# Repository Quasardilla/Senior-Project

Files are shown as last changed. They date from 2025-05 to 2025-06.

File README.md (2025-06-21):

# Haptic Feedback Remote
This "remote" is a design concept that utilizes a touchpad as opposed to a D-pad with the intention to control a tv (although this concept doesn't include any of the hardware required for communication). Based on inputs, the remote will vibrate in specific patterns (haptic feedback) in order to simulate certain feelings like a click or a scroll. 

# Features
Click: When the touchpad is pressed and released, the voice coil will give a kick accompanied by a little chirp

Scroll: When the touchpad is pressed and moved across, the voice coil gives a very light kick for every movement in the X or Y direction

Simulated Scroll: When the touchpad is being scrolled across, and the user lets go, the micro calculates how often a scroll click should happen given the velocity of the movement before it was released. The voice coil reacts as though it's scrolling from an actual interaction

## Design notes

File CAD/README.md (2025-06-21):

# CAD
All of the models that were used in this project were designed in OnShape. Since the platform doesn't export entire projects, I won't post the files here.
You can check out the CAD at [OnShape](https://cad.onshape.com/documents/ba6eefc270d24b4c9dd6e786/w/6963f8d8a0a2caa2323001ec/e/34bf19d81762a19b936466c0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), and if you make an account you can download all the models.

## The CAD includes:

The shell (top and bottom), which slides together

The touchpad bracket that keeps the touchpad in place

Demo pcb's so I could figure out how the pcbs would fit before I ordered them

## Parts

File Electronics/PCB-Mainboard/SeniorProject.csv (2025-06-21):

Reference | Qty | Value | DNP | Exclude from BOM | Exclude from Board | Footprint | Datasheet
C1,C2 | 2 | 0.1uF |  |  |  | Capacitor_SMD:C_0201_0603Metric | ~
C3,C4 | 2 | 10uF |  |  |  | Capacitor_SMD:CP_Elec_4x4.5 | ~
J1 | 1 | 1-2483180-2 |  |  |  | SamacSys IMPORTED:1-2483180-2 | https://www.te.com/commerce/DocumentDelivery/DDEController?Action=showdoc
M1 | 1 | Motor_DC |  |  |  | Resistor_SMD:R_2816_7142Metric_Pad3.20x4.45mm_HandSolder | ~
Q1 | 1 | SS8550 |  |  |  | Package_TO_SOT_SMD:SOT-416 | http://www.secosgmbh.com/datasheet/products/SSMPTransistor/SOT-23/SS8550.pdf
R1,R3,R4 | 3 | 10k |  |  |  | Resistor_SMD:R_0201_0603Metric | ~
R2 | 1 | 75k |  |  |  | Resistor_SMD:R_0201_0603Metric | ~
R5,R6 | 2 | R |  |  |  | Resistor_SMD:R_0201_0603Metric | ~
R7,R8 | 2 | 100 |  |  |  | Resistor_SMD:R_0201_0603Metric | ~
STRAIN1,STRAIN2 | 2 | ~ |  |  |  | Resistor_SMD:R_2816_7142Metric_Pad3.20x4.45mm_HandSolder | ~
U1 | 1 | Teensy 4.0 |  |  |  | Teensy 4.0:MODULE_Teensy 4.0
U2 | 1 | HX711 |  |  |  | Package_SO:SOP-16_3.9x9.9mm_P1.27mm | https://web.archive.org/web/20220615044707/https://akizukidenshi.com/download/ds/avia/hx711.pdf
U3 | 1 | MPR121QR2 |  |  |  | Package_DFN_QFN:UQFN-20_3x3mm_P0.4mm | https://resurgentsemi.com/wp-content/uploads/2018/09/MPR121_rev5-Resurgent.pdf?d453f8&d453f8

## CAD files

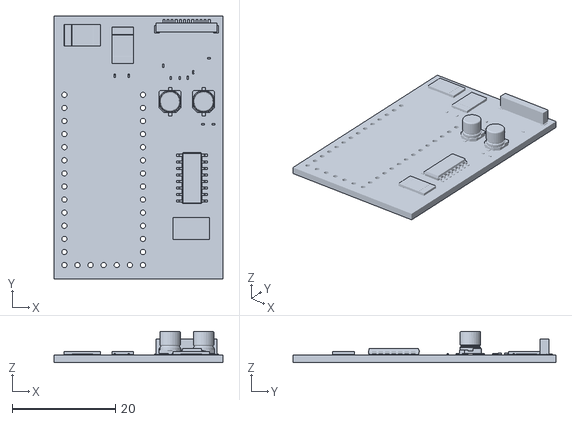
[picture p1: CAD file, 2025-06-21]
Electronics/PCB-Mainboard/SeniorProject.stl
32.8 x 51.0 x 6.09

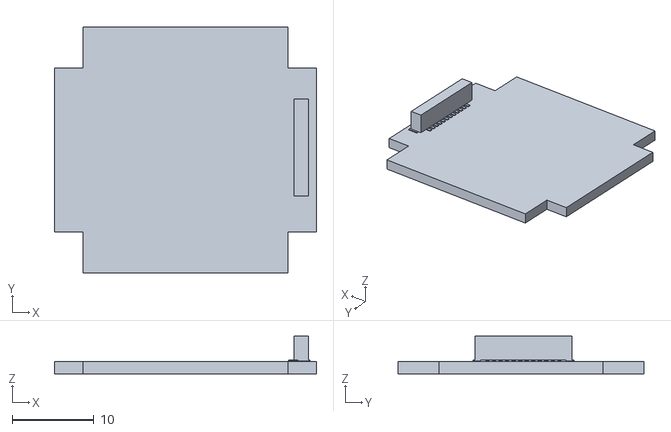
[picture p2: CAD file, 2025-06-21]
Electronics/PCB-Touchpad/SeniorProjectTouchpad.stl
32.0 x 30.0 x 4.59

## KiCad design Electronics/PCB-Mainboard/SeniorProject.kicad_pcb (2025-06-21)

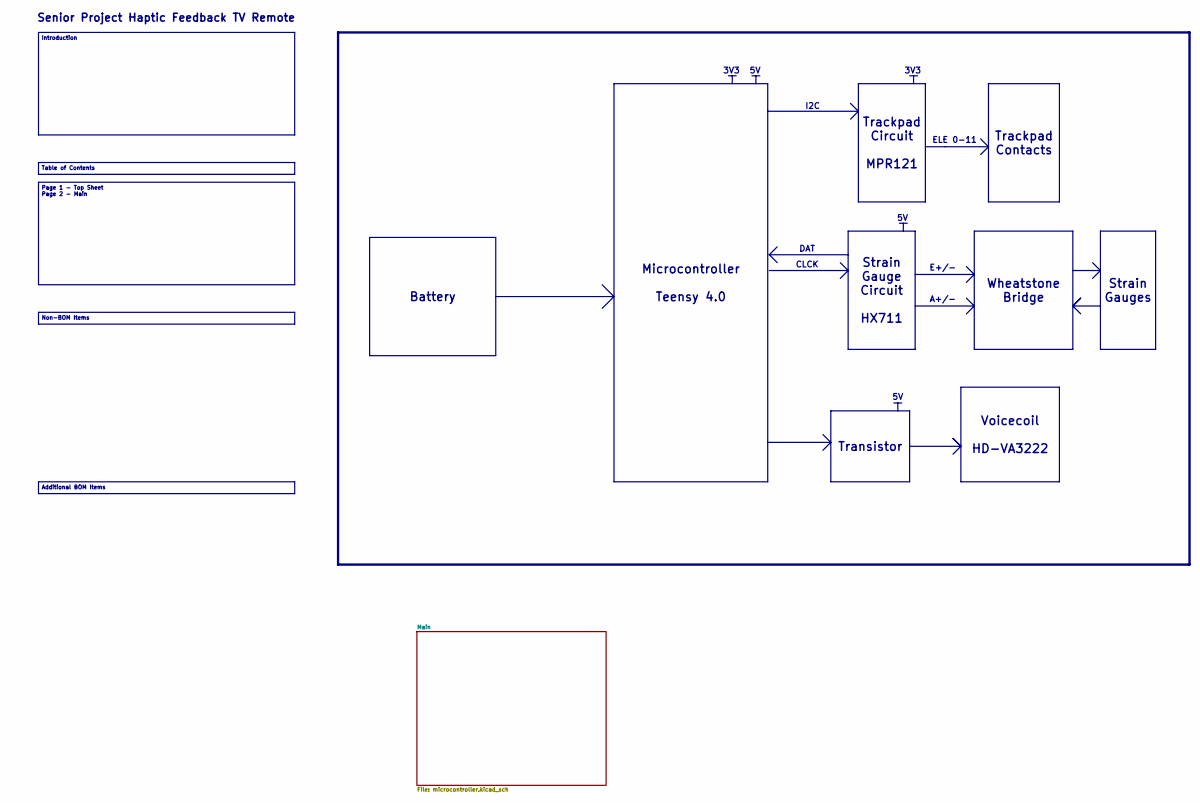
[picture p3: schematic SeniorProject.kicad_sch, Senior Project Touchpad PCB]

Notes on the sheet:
A+/-
CLCK
ELE 0-11
3V3
I2C
E+/-
Senior Project Haptic Feedback TV Remote
DAT
Table of Contents
Battery
Transistor
Trackpad Contacts
Voicecoil HD-VA3222
Introduction
Microcontroller Teensy 4.0
Page 1 - Top Sheet Page 2 - Main
Wheatstone Bridge
Additional BOM Items
Trackpad Circuit MPR121
Strain Gauges
Strain Gauge Circuit HX711
Non-BOM Items

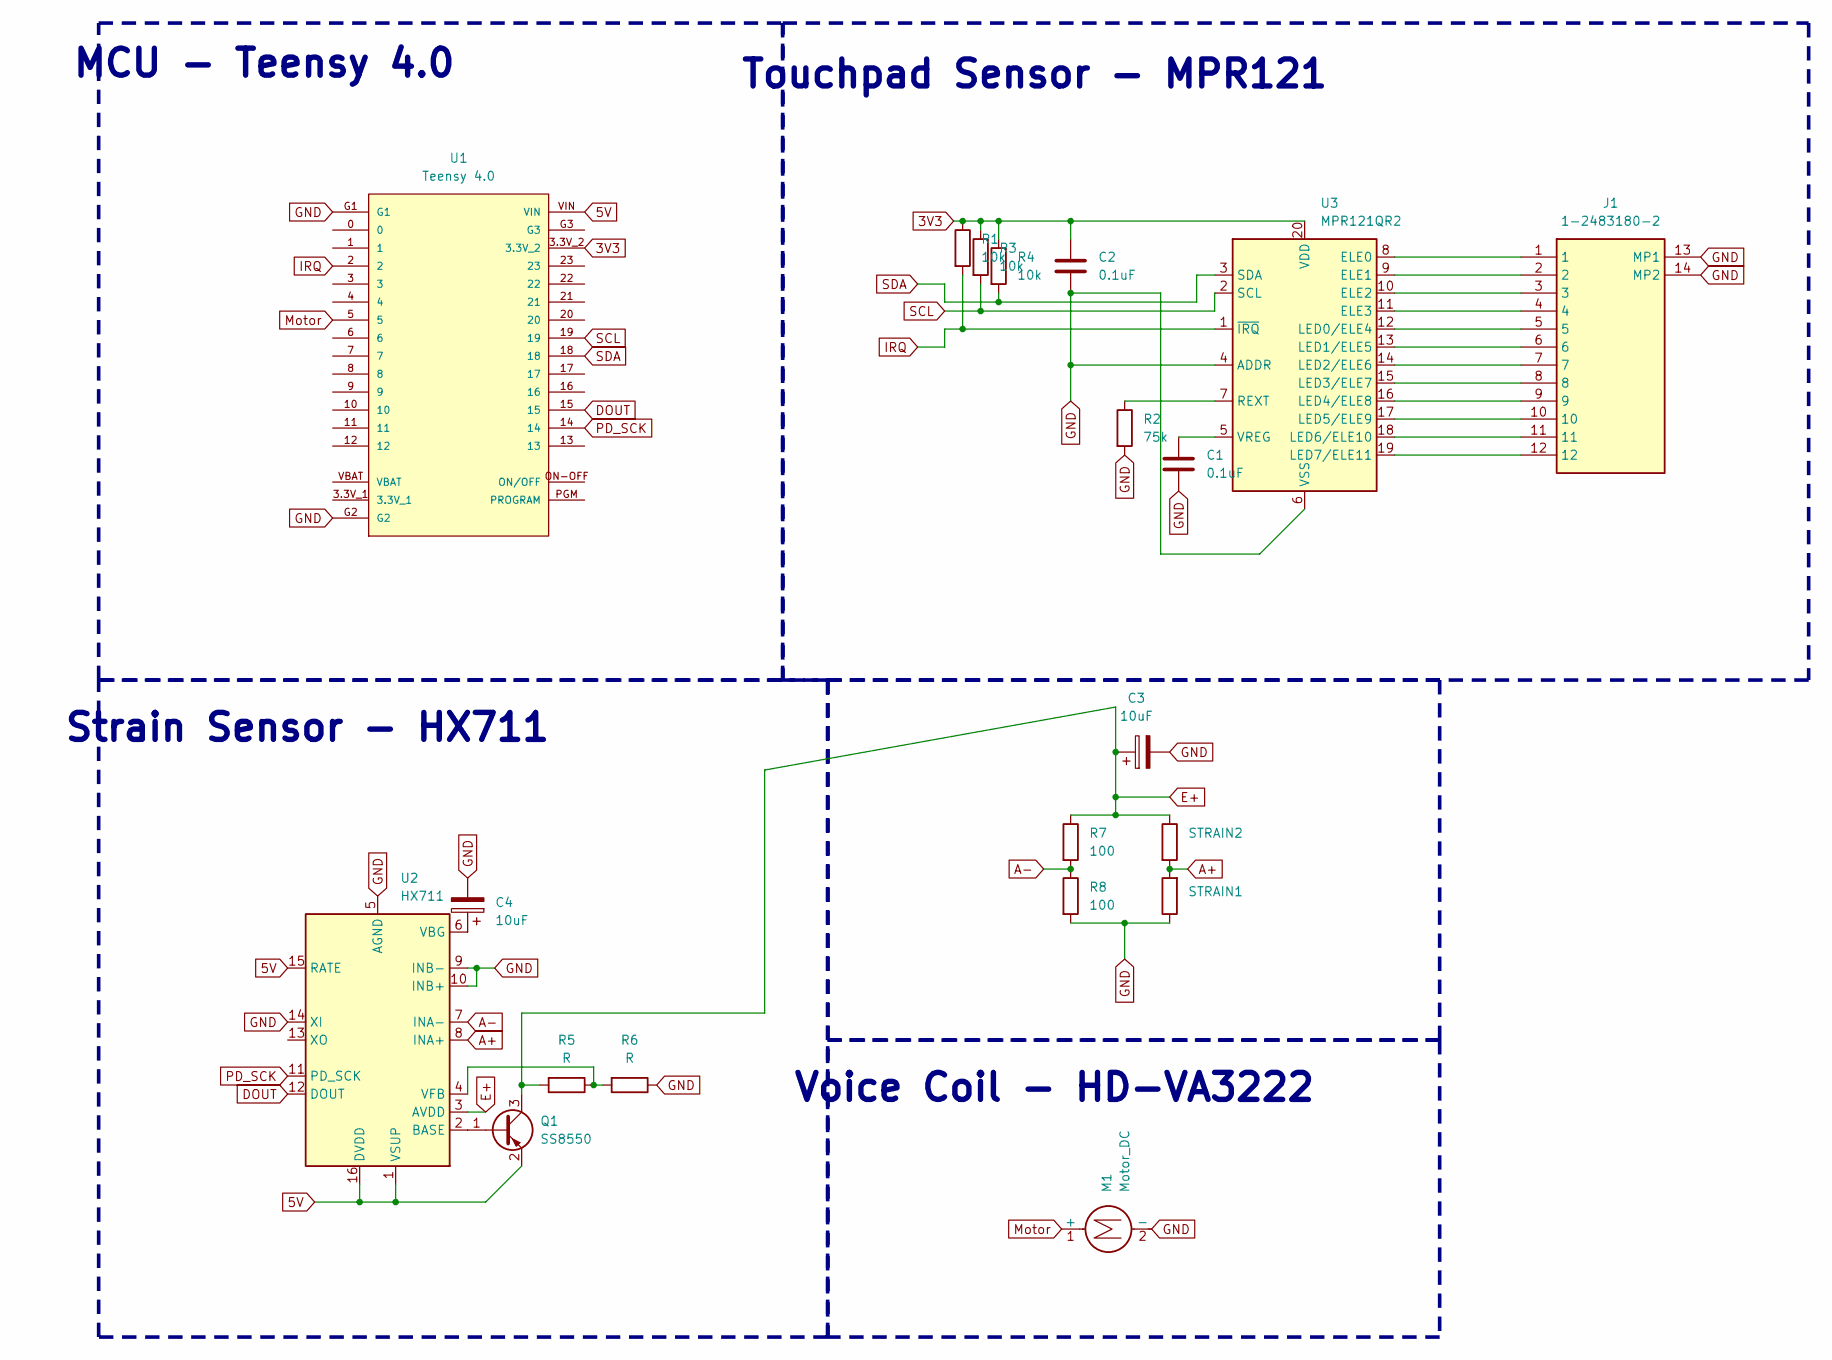
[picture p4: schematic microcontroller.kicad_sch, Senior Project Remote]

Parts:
C1, C2: 0.1uF; C_0201_0603Metric
C3, C4: 10uF; CP_Elec_4x4.5
J1: 1-2483180-2; Manufacturer_Part_Number 1-2483180-2; Mouser Part Number 571-1-2483180-2
M1: Motor_DC; R_2816_7142Metric_Pad3.20x4.45mm_HandSolder
Q1: SS8550; SOT-416
R1, R3, R4: 10k; R_0201_0603Metric
R2: 75k; R_0201_0603Metric
R5, R6: R; R_0201_0603Metric
R7, R8: 100; R_0201_0603Metric
STRAIN1, STRAIN2: R_2816_7142Metric_Pad3.20x4.45mm_HandSolder
U1: Teensy 4.0; MODULE_Teensy 4.0
U2: HX711; SOP-16_3.9x9.9mm_P1.27mm
U3: MPR121QR2; UQFN-20_3x3mm_P0.4mm

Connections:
3V3: C2.1, R1.1, R3.1, R4.1, U1.3.3V_2, U3.20 (VDD)
5V: Q1.2 (E), U1.VIN, U2.1 (VSUP), U2.15 (RATE), U2.16 (DVDD)
A+: STRAIN1.2, STRAIN2.2, U2.8 (INA+)
A-: R7.2, R8.1, U2.7 (INA-)
DOUT: U1.15, U2.12 (DOUT)
E+: C3.1, Q1.3 (C), R5.2, R7.1, STRAIN2.1, U2.3 (AVDD)
IRQ: R1.2, U1.2, U3.1 (~IRQ)
unnamed: Q1.1 (B), U2.2 (BASE)
unnamed: C4.1, U2.6 (VBG)
unnamed: R5.1, R6.2, U2.4 (VFB)
unnamed: J1.1, U3.8 (ELE0)
unnamed: J1.2, U3.9 (ELE1)
unnamed: J1.3, U3.10 (ELE2)
unnamed: J1.4, U3.11 (ELE3)
unnamed: J1.5, U3.12 (LED0/ELE4)
unnamed: J1.6, U3.13 (LED1/ELE5)
unnamed: J1.7, U3.14 (LED2/ELE6)
unnamed: J1.8, U3.15 (LED3/ELE7)
unnamed: J1.9, U3.16 (LED4/ELE8)
unnamed: J1.10, U3.17 (LED5/ELE9)
unnamed: J1.11, U3.18 (LED6/ELE10)
unnamed: J1.12, U3.19 (LED7/ELE11)
unnamed: R2.1, U3.7 (REXT)
unnamed: C1.1, U3.5 (VREG)
PD_SCK: U1.14, U2.11 (PD_SCK)
SCL: R3.2, U1.19, U3.2 (SCL)
SDA: R4.2, U1.18, U3.3 (SDA)

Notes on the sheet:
Touchpad Sensor - MPR121
MCU - Teensy 4.0
Strain Sensor - HX711
Voice Coil - HD-VA3222

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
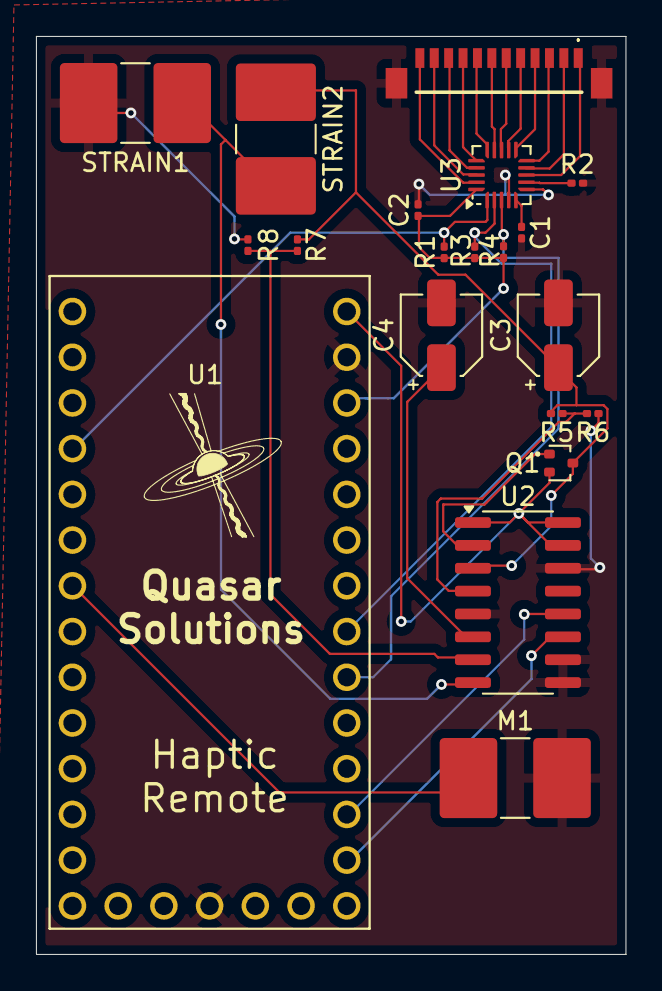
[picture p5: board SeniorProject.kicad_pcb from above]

Board: 2 copper layers, 32.8 x 51.0 mm, 20 parts (0 on the bottom side), 29 nets.

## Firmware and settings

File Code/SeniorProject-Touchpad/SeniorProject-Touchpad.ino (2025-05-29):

/*Copyright (c) 2010 bildr community

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
 THE SOFTWARE IS PROVIDED "AS IS", WITHOUT WARRANTY OF ANY KIND, EXPRESS OR
 IMPLIED, INCLUDING BUT NOT LIMITED TO THE WARRANTIES OF MERCHANTABILITY,
 FITNESS FOR A PARTICULAR PURPOSE AND NONINFRINGEMENT. IN NO EVENT SHALL THE
 AUTHORS OR COPYRIGHT HOLDERS BE LIABLE FOR ANY CLAIM, DAMAGES OR OTHER
 LIABILITY, WHETHER IN AN ACTION OF CONTRACT, TORT OR OTHERWISE, ARISING FROM,
 OUT OF OR IN CONNECTION WITH THE SOFTWARE OR THE USE OR OTHER DEALINGS IN
 THE SOFTWARE.
*/

#include "mpr121.h"
#include <Wire.h>

int M_PIN = 5;  //Motor Pin

int irqpin = 2;           // Digital 2
boolean touchStates[12];  //to keep track of the previous touch states
boolean touchPad[5][5];   //to keep track of the previous touch states

boolean isPressed = false;
boolean isScrolling = false;

int startPressing = 0;
int stopPressing = 0;
elapsedMillis oldCounter = 0; // used to time setting oldX & oldY so that it happens once per second

float oldX = 0; // X from scrollSampleFrame/2 ago, no matter how many readings
float oldY = 0;
float ppX = 0;  //previous PREVIOUS x
float ppY = 0;
float pX = 0;  //previous x
float pY = 0;
float X = NAN;  // x -- NaN so it doesn't start clicked
float Y = NAN;

float vX;  // change between x and pX
float vY;
float pvX;  // change between pX and ppX
float pvY;

float aX;  // change between vx and pvx
float aY;

float scrollVX = 0; // change between X and oldX over "scrollTimeFrame," not over the length of the loop -- this makes it easier to flick the scroll
float scrollVY = 0;

float simulatedScrollVX = 0;
float simulatedScrollVY = 0;

float simulatedScrollX = 0;
float simulatedScrollY = 0;

const float scrollDecel = 0.025; // How fast the simulated scroll loses speed
const int scrollSampleFrame = 200; // How long the scrollVX and VY are calculated across 
const int scrollTimeFrame = 40; // How often the simulated scroll should be calculated
const int simulatedScrollResolution = 2; // The interval for scroll wheel ticks, bigger numbers lead to less vibration

int xClickInterval = 0; // Allows me to track the last time the scroll wheel "ticked," so it doesn't tick multiple timers per the "simulatedScrollResolution"
int yClickInterval = 0;

void setup() {
  pinMode(irqpin, INPUT);
  digitalWrite(irqpin, HIGH);  //enable pullup resistor

  Serial.begin(9600);
  Wire.begin();

  mpr121_setup();

  playStartupSound();
}



void loop() {
  if(oldCounter % scrollSampleFrame == 0) {
    oldX = X;
    oldY = Y;
  }

  if(oldCounter % scrollTimeFrame == 0 && isScrolling) {
    updateSimulatedScroll();
  }

  setPreviousPositions();

  readTouchInputs();

  calcVelocities();

  if(oldCounter % scrollSampleFrame == (scrollSampleFrame / 2)) { // Using the middle of the scroll time frame because if I did it at the end there would be issues with the velocity
    calcScrollVelocities();

    if(abs(simulatedScrollVX) > 0 || abs(simulatedScrollVY) > 0) {
      Serial.print(simulatedScrollX);
      Serial.print(" ");
      Serial.print(simulatedScrollY);
      Serial.print(" ");
      Serial.print(simulatedScrollVX);
      Serial.print(" ");
      Serial.print(simulatedScrollVY);
      Serial.print(" ");
      Serial.print(isScrolling);
      Serial.print(" ");
      Serial.print(isPressed);
      Serial.print("    ---   ");
      Serial.print(millis());
      Serial.println();
    }
  }


  calcAccelerations();

  if (!std::isnan(X) || !std::isnan(Y)) { // If there's some reading on the touchpad
    // Serial.print("X:");
    // Serial.print(X, 2);
    // Serial.print(" Y:");
    // Serial.print(Y, 2);
    // Serial.print(" vX:");
    // Serial.print(vX, 2);
    // Serial.print(" vY:");
    // Serial.print(vY, 2);
    // Serial.print(" aX:");
    // Serial.print(aX, 2);
    // Serial.print(" aY:");
    // Serial.println(aY, 2);

    if (!isPressed && !isScrolling) {
      startPressing = millis();
      isPressed = true;
      clickPress();
    } else if (abs(simulatedScrollVX) > 0 || abs(simulatedScrollVY) > 0) { // "Catches" the scroll wheel when you tap the pad
      isPressed = true;
      resetSimulatedScroll();
    }

    if (millis() - startPressing > 100 && ((vX != 0 && !std::isnan(vX)) || (vY != 0 && !std::isnan(vY)))) {
      isScrolling = true;
    }
 
  } else { // If there's no reading on the touchpad
    if (isPressed && (abs(scrollVX) > 0.5 || abs(scrollVY) > 0.5)){
      isPressed = false;
      isScrolling = true;
      clearPosInfo();

      simulatedScrollVX = scrollVX; // + 1 - 1 so that the references in memory are different
      simulatedScrollVY = scrollVY;


    } else if (isPressed) {
      isPressed = false;
      stopPressing = millis();
      clearPosInfo();

      if (stopPressing - startPressing > 50 && stopPressing - startPressing < 1000 && !isScrolling) {
        clickRelease();
      }

      startPressing = 0;
      stopPressing = 0;
    } else if (isScrolling && abs(scrollVX) < 1 && abs(scrollVY) < 1) {
      isScrolling = false;
    }
  }

  if (isScrolling && X > 0 && X < 4 && Y > 0 && Y < 4 && ((vX != 0 && !std::isnan(vX)) || (vY != 0 && !std::isnan(vY)))) {
    scrollClick();
  } else if (isScrolling && !isPressed && (abs(simulatedScrollVX) > 0.0001 || abs(simulatedScrollVY) > 0.0001)) {
    playSimulatedScroll();
  }

  if(isScrolling)
    delay(0); // Allows the touchpad to be reactive of MUCH higher speeds -- 5x faster than normal (there's a 400 microSecond delay from each scroll tick)
  else
    delay(2);
}


void readTouchInputs() {
  if (!checkInterrupt()) {

    //read the touch state from the MPR121
    Wire.requestFrom(0x5A, 2);

    byte LSB = Wire.read();
    byte MSB = Wire.read();

    uint16_t touched = ((MSB << 8) | LSB);  //16bits that make up the touch states

    for (int i = 0; i < 12; i++) {  // Check what electrodes were pressed
      if (touched & (1 << i)) {
        touchStates[i] = 1;
      } else {
        touchStates[i] = 0;
      }
    }

    X = calculateAverage(0, touchStates);
    Y = calculateAverage(5, touchStates);
  }
}

float calculateAverage(int offset, boolean* arr) {
  int total = 0;
  int count = 0;

  for (int i = 0 + offset; i < 5 + offset; i++) {
    if (arr[i]) {
      count++;
      total += (i - offset);
    }
  }

  return (float)total / (float)count;
}


void mpr121_setup(void) {

  set_register(0x5A, ELE_CFG, 0x00);

  // Section A - Controls filtering when data is > baseline.
  set_register(0x5A, MHD_R, 0x01);
  set_register(0x5A, NHD_R, 0x01);
  set_register(0x5A, NCL_R, 0x00);
  set_register(0x5A, FDL_R, 0x00);

  // Section B - Controls filtering when data is < baseline.
  set_register(0x5A, MHD_F, 0x01);
  set_register(0x5A, NHD_F, 0x01);
  set_register(0x5A, NCL_F, 0xFF);
  set_register(0x5A, FDL_F, 0x02);

  // Section C - Sets touch and release thresholds for each electrode
  set_register(0x5A, ELE0_T, TOU_THRESH);
  set_register(0x5A, ELE0_R, REL_THRESH);

  set_register(0x5A, ELE1_T, TOU_THRESH);
  set_register(0x5A, ELE1_R, REL_THRESH);

  set_register(0x5A, ELE2_T, TOU_THRESH);
  set_register(0x5A, ELE2_R, REL_THRESH);

  set_register(0x5A, ELE3_T, TOU_THRESH);
  set_register(0x5A, ELE3_R, REL_THRESH);

  set_register(0x5A, ELE4_T, TOU_THRESH);
  set_register(0x5A, ELE4_R, REL_THRESH);

  set_register(0x5A, ELE5_T, TOU_THRESH);
  set_register(0x5A, ELE5_R, REL_THRESH);

  set_register(0x5A, ELE6_T, TOU_THRESH);
  set_register(0x5A, ELE6_R, REL_THRESH);

  set_register(0x5A, ELE7_T, TOU_THRESH);
  set_register(0x5A, ELE7_R, REL_THRESH);

  set_register(0x5A, ELE8_T, TOU_THRESH);
  set_register(0x5A, ELE8_R, REL_THRESH);

  set_register(0x5A, ELE9_T, TOU_THRESH);
  set_register(0x5A, ELE9_R, REL_THRESH);

  set_register(0x5A, ELE10_T, TOU_THRESH);
  set_register(0x5A, ELE10_R, REL_THRESH);

  set_register(0x5A, ELE11_T, TOU_THRESH);
  set_register(0x5A, ELE11_R, REL_THRESH);

  // Section D
  // Set the Filter Configuration
  // Set ESI2
  set_register(0x5A, FIL_CFG, 0x04);

  // Section E
  // Electrode Configuration
  // Set ELE_CFG to 0x00 to return to standby mode
  set_register(0x5A, ELE_CFG, 0x0C);  // Enables all 12 Electrodes


  // Section F
  // Enable Auto Config and auto Reconfig
  /*set_register(0x5A, ATO_CFG0, 0x0B);
  set_register(0x5A, ATO_CFGU, 0xC9);  // USL = (Vdd-0.7)/vdd*256 = 0xC9 @3.3V   set_register(0x5A, ATO_CFGL, 0x82);  // LSL = 0.65*USL = 0x82 @3.3V
  set_register(0x5A, ATO_CFGT, 0xB5);*/
  // Target = 0.9*USL = 0xB5 @3.3V

  set_register(0x5A, ELE_CFG, 0x0C);
}


boolean checkInterrupt(void) {
  return digitalRead(irqpin);
}


void set_register(int address, unsigned char r, unsigned char v) {
  Wire.beginTransmission(address);
  Wire.write(r);
  Wire.write(v);
  Wire.endTransmission();
}

void pulseMotor(int val, int millis) {
  if (val > 155) {
    Serial.println("----- INVALID MOTOR VAL -----");
    return;
  }

  analogWrite(M_PIN, val);  // 155 is the MAXIMUM for the voice coil
  delay(millis);
  analogWrite(M_PIN, 0);  // 155 is the MAXIMUM for the voice coil
  delay(millis);
}

void playStartupSound() {
  for (int i = 0; i < 12; i++)
    pulseMotor(10, 6);
  for (int i = 0; i < 20; i++)
    pulseMotor(15, 4);
  for (int i = 0; i < 40; i++)
    pulseMotor(20, 2);
}

void scrollClick() {
  analogWrite(M_PIN, -1);  // 155 is the MAXIMUM for the voice coil
  delayMicroseconds(400);
  analogWrite(M_PIN, 0);  // 155 is the MAXIMUM for the voice coil
  Serial.println("----- CLICK CLICK -----");
}

void clickPress() {
  analogWrite(M_PIN, -1);  // 155 is the MAXIMUM for the voice coil
  delayMicroseconds(1200);
  analogWrite(M_PIN, 0);  //
}

void clickRelease() {
  Serial.println("CLICK");

  pulseMotor(15, 8);
  pulseMotor(-155, 4);
}

void setPreviousPositions() {
  ppX = pX;
  ppY = pY;
  pX = X;
  pY = Y;
}

void calcVelocities() {

  if(!std::isnan(X) && !std::isnan(pX))
    vX = X - pX;

  if(!std::isnan(Y) && !std::isnan(pY))
    vY = Y - pY;

  if(!std::isnan(pX) && !std::isnan(ppX))
    pvX = pX - ppX;

  if(!std::isnan(pY) && !std::isnan(ppY))
    pvY = pY - ppY;
}

void calcScrollVelocities() {
    if(!std::isnan(X) && !std::isnan(oldX))
      scrollVX = X - oldX;

    if(!std::isnan(Y) && !std::isnan(oldY))
      scrollVY = Y - oldY;
}

void calcAccelerations() {
  if(!std::isnan(vX) && !std::isnan(pvX))
    aX = vX - pvX;
  
  if(!std::isnan(vY) && !std::isnan(pvY))
    aY = vY - pvY;
}

void updateSimulatedScroll() {
  simulatedScrollX += simulatedScrollVX;
  simulatedScrollY += simulatedScrollVY;

  if(simulatedScrollVX > scrollDecel / 5000) {
    simulatedScrollVX -= scrollDecel;
  } else if(simulatedScrollVX < -scrollDecel / 5000) {
    simulatedScrollVX += scrollDecel;
  }

  if(simulatedScrollVY > scrollDecel / 5000) {
    simulatedScrollVY -= scrollDecel;
  } else if(simulatedScrollVY < -scrollDecel / 5000) {
    simulatedScrollVY += scrollDecel;
  }

  if(!isPressed && abs(simulatedScrollVX) < 0.001 && abs(simulatedScrollVY) < 0.001) {
    isScrolling = false;
  }
}

void playSimulatedScroll() {
  if((int) (simulatedScrollX / simulatedScrollResolution) != xClickInterval || (int) (simulatedScrollY / simulatedScrollResolution) != yClickInterval) { // || (int) (simulatedScrollY * 10000) % (200 * 10000) == 0
    xClickInterval = (int) (simulatedScrollX / simulatedScrollResolution);
    yClickInterval = (int) (simulatedScrollY / simulatedScrollResolution);
    scrollClick();
  } else {
    delayMicroseconds(400);
  }
}

void resetSimulatedScroll() {
  isScrolling = false;

  simulatedScrollVX = 0;
  simulatedScrollVY = 0;
  simulatedScrollX = 0;
  simulatedScrollY = 0;
  scrollVX = 0;
  scrollVY = 0;
  oldX = X;
  oldY = Y;
}

void clearPosInfo() {
  ppX = 0;  //previous PREVIOUS x
  ppY = 0;
  pX = 0;  //previous x
  pY = 0;
  X = NAN;  // x -- NaN so it doesn't start clicked
  Y = NAN;

  vX = NULL;  // change between x and pX
  vY = NULL;
  pvX = NULL;  // change between pX and ppX
  pvY = NULL;

  aX = NULL;  // change between vx and pvx
  aY = NULL;
}
